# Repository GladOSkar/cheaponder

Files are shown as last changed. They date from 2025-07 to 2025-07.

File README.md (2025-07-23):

The idea is to put an ESP32 S3 Mini together with a Li-Ion charger and a 3.3V buck-boost regulator into this case:

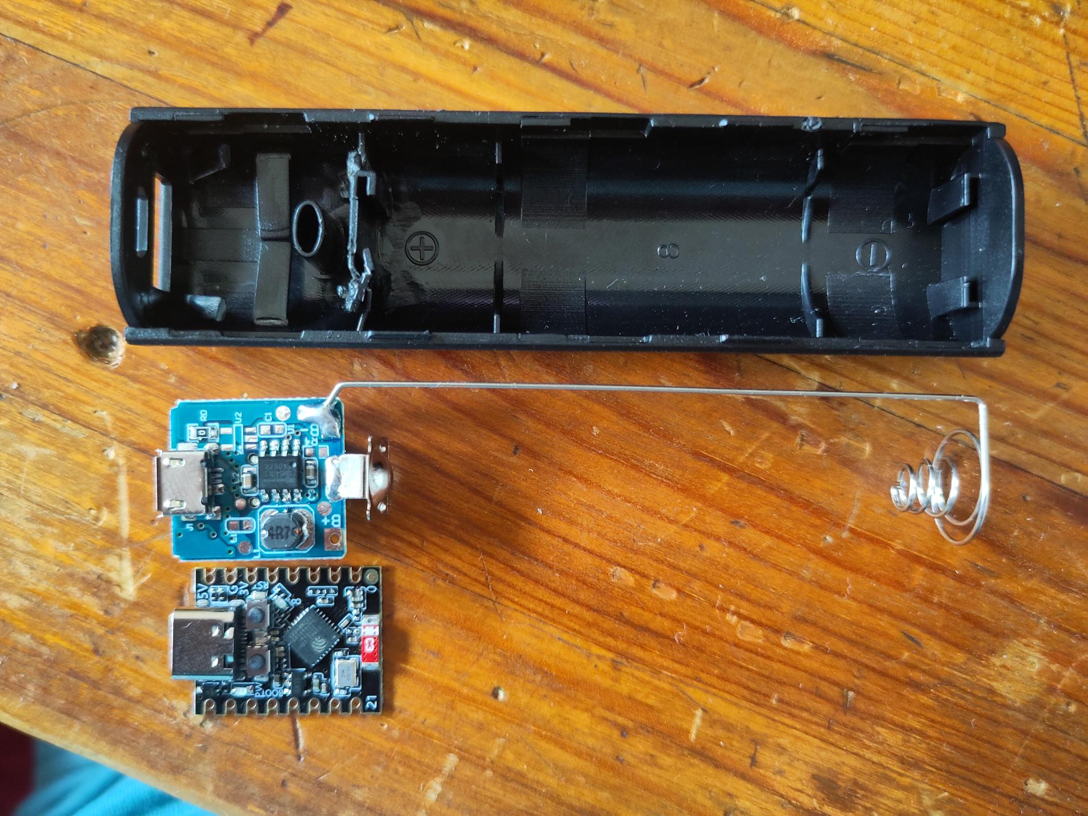
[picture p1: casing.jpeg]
Casing


So i'm going to put a small PCB on the backside of the ESP32 module:

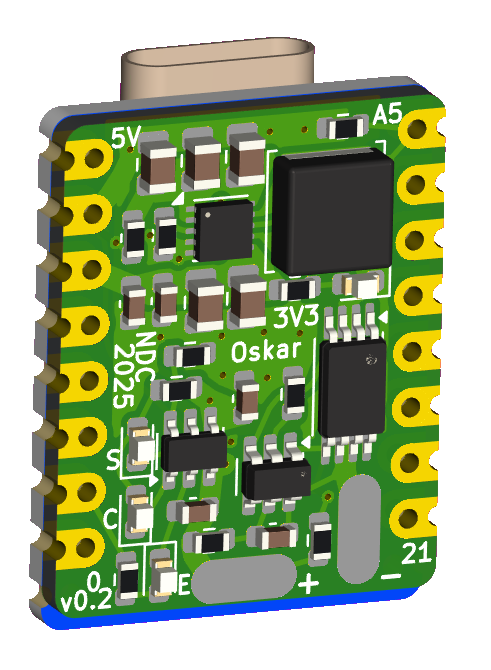
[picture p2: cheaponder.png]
PCB Preview


I already tested it and even though it's tight, it should fit.

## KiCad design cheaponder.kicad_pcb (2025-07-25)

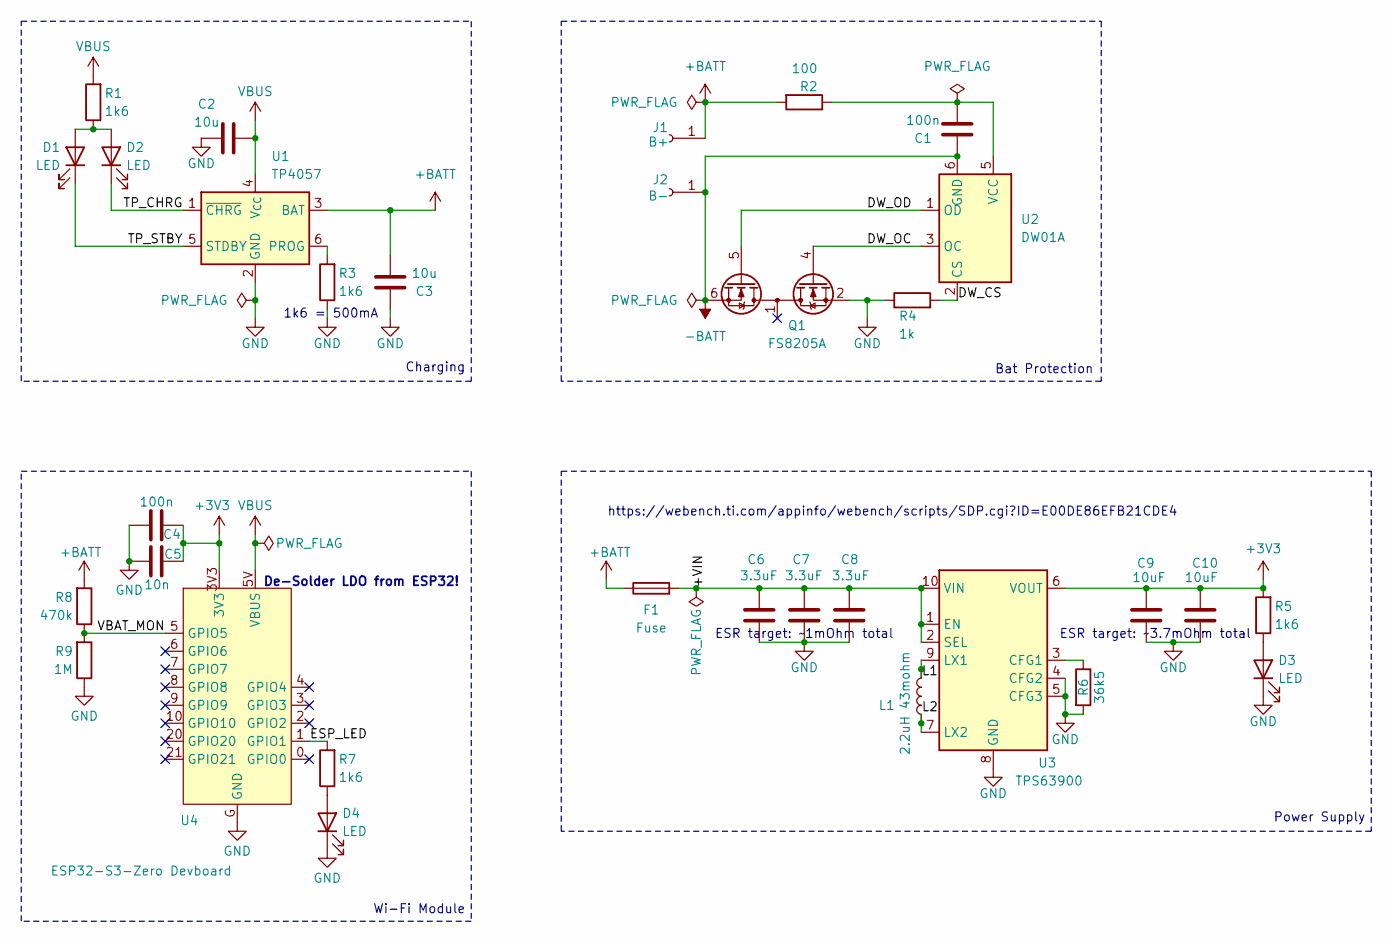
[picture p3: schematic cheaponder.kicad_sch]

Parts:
C1, C4: 100n; C_0603_1608Metric
C2: 10u; C_0603_1608Metric
C3: 10u; C_0805_2012Metric
C5: 10n; C_0603_1608Metric
C6, C7, C8: 3.3uF; C_0805_2012Metric
C9, C10: 10uF; C_0805_2012Metric
D1, D2, D3, D4: LED; LED_0603_1608Metric
F1: Fuse; Fuse_0603_1608Metric
J1: B+; pbwire
J2: B-; pbwire
L1: 2.2uH 43mohm; L_Changjiang_FNR5020S
Q1: FS8205A; TSSOP-8_4.4x3mm_P0.65mm
R1, R3, R5, R7: 1k6; R_0603_1608Metric
R2: 100; R_0603_1608Metric
R4: 1k; R_0603_1608Metric
R6: 36k5; R_0603_1608Metric
R8: 470k; R_0603_1608Metric
R9: 1M; R_0603_1608Metric
U1: TP4057; TSOT-23-6
U2: DW01A; SOT-23-6
U3: TPS63900; WSON-10-1EP_2.5x2.5mm_P0.5mm_EP1.2x2mm_ThermalVias
U4: ESP32-S3-Zero Devboard; ESP32_C3_SuperMini

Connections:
+3V3: C4.2, C5.1, C9.2, C10.2, R5.2, U3.6 (VOUT), U4.3V3
+BATT: C3.2, F1.1, J1.1, R2.2, R8.2, U1.3 (BAT)
-BATT: C1.1, J2.1, Q1.6 (S2), Q1.7 (S2), U2.6 (GND)
/+VIN: C6.2, C7.2, C8.2, F1.2, U3.1 (EN), U3.2 (SEL), U3.10 (VIN)
/DW_CS: R4.2, U2.2 (CS)
/DW_OC: Q1.4 (G1), U2.3 (OC)
/DW_OD: Q1.5 (G2), U2.1 (OD)
/ESP_LED: R7.2, U4.1 (GPIO1)
/L1: L1.2, U3.9 (LX1)
/L2: L1.1, U3.7 (LX2)
/TP_CHRG: D2.1 (K), U1.1 (~CHRG)
/TP_STBY: D1.1 (K), U1.5 (STDBY)
/VBAT_MON: R8.1, R9.2, U4.5 (GPIO5)
GND: C2.1, C3.1, C4.1, C5.2, C6.1, C7.1, C8.1, C9.1, C10.1, D3.1 (K), D4.1 (K), Q1.2 (S1), Q1.3 (S1), R3.1, R4.1, R6.2, R9.1, U1.2 (GND), U3.4 (CFG2), U3.5 (CFG3), U3.8 (GND), U3.11 (GND), U4.G (GND)
unnamed: D1.2 (A), D2.2 (A), R1.1
unnamed: D3.2 (A), R5.1
unnamed: D4.2 (A), R7.1
unnamed: R3.2, U1.6 (PROG)
unnamed: C1.2, R2.1, U2.5 (VCC)
unnamed: R6.1, U3.3 (CFG1)
VBUS: C2.2, R1.2, U1.4 (V_{CC}), U4.5V (VBUS)

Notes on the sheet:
De-Solder LDO from ESP32!
Charging
ESR target: ~1mOhm total
1k6 = 500mA
Power Supply
Wi-Fi Module
Bat Protection
ESR target: ~3.7mOhm total
https://webench.ti.com/appinfo/webench/scripts/SDP.cgi?ID=E00DE86EFB21CDE4

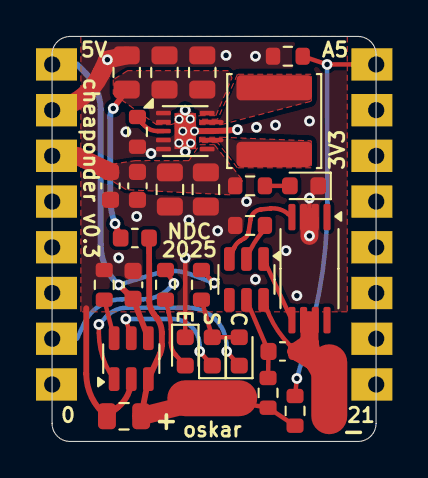
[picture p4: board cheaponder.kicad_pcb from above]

Board: 2 copper layers, 18.0 x 22.5 mm, 32 parts (1 on the bottom side), 21 nets.

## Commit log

2025-07-21 Update to KiCAD 9
    [cheaponder.kicad_pcb, cheaponder.kicad_sch]
2025-07-21 Fix link and add comment
    [cheaponder.kicad_sch]
2025-07-23 Implement some of Max' Feedback
    [cheaponder.kicad_pcb]
2025-07-23 New 3D model for ESP, photos, Readme
    [cheaponder.kicad_pcb]
2025-07-24 Relayout to accomodate bigger cap and put LEDs where we can see them
    [cheaponder.kicad_pcb, cheaponder.kicad_sch]
2025-07-25 Add comment and fix trace distance
    [cheaponder.kicad_pcb]
